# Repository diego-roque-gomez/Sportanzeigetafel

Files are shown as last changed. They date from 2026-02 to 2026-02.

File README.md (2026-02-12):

# Sports scoreboard
Development of a functional prototype for a sports scoreboard

This project was developed in collaboration with the sports department at Tecnológico de Monterrey and focused on the construction of an electronic scoreboard for the university's American football stadium.

## Requirements ##
- High visibility under outdoor lighting conditions
- Weather-resistant structure
- Secure mounting in the stadium cabin
- Remote control capability

## System overview ##
A functional prototype was designed, manufactured and submitted to the campus sports director for evaluation.

The system implemented an IoT-based architecture in which an ESP32 microcontroller received wireless commands from a web interface, enabling remote control of the scoreboard.

## Technical Contributions ##
- Design of a customised circuit board with multiple 7-segment displays and 8x8 LED matrices
- Implementation of MAX7219 drivers for efficient display control and GPIO optimisation
- Hardware integration with ESP32
- Collaboration on the design of a retractable mechanical mechanism for deployment and environmental protection

## Images
### PCB
Front_view_of_the_PCB
Rear_view_of_the_PCB
PCB_Layout

### Prototype
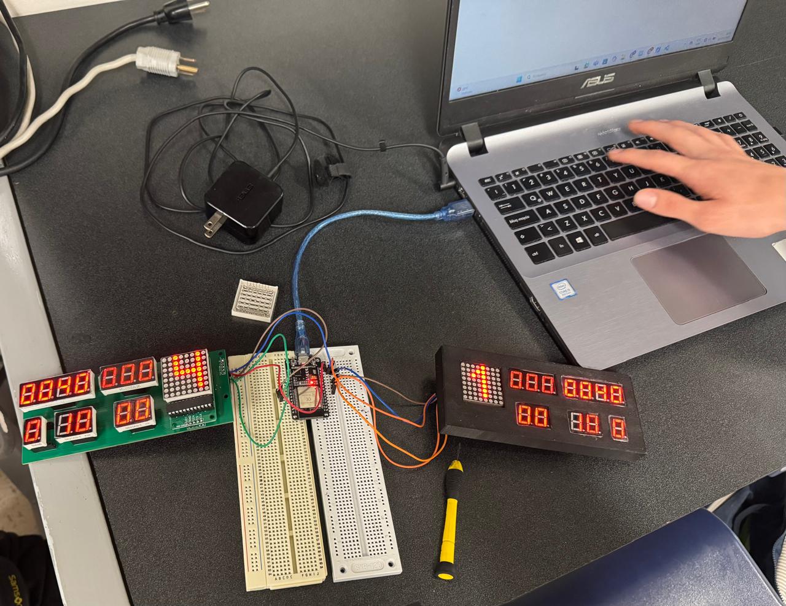
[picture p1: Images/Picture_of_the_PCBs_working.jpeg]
Picture of the PCBs working

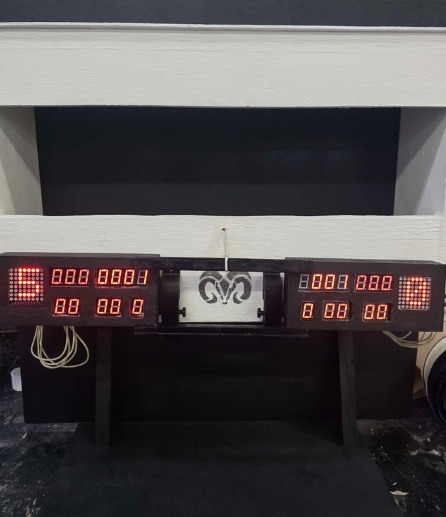
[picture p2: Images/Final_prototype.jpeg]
Final Prototype


## Demonstration videos

[Video_of_the_PCB_working](https://github.com/user-attachments/assets/36a9706f-3883-4caf-9d38-b58036e7d53b)

[Video of the final prototype](https://github.com/user-attachments/assets/bcdd5858-99ae-4861-a208-e2463b085100)

## System Architecture & Team Responsibilities

The project was developed collaboratively with clearly defined responsibilities:

- **PCB design and Electronic Integration:**

  Diego Roque Gómez

- **Financial proposal design for the project:**
  
  César Santiago Marín Barrera (included with permission)
  
  David Martínez Millán (included with permission)

- **Prototype assembly and installation:**

  Antoine Aramis Guzmán Rocha (included with permission)

- **Mechanical CAD design (SolidWorks):**
  
  Rodrigo Pérez Cázares (included with permission)
  
  Antoine Aramis Guzmán Rocha (included with permission)
  
  Diego Roque Gómez
  
- **Design and programming of the web interface and ESP32:**

  Rodrigo Pérez Cázares

## Mechanical design
The mechanical structure was developed collaboratively through iterative design cycles.

Individual components were modeled separately and later integrated into a unified assembly. The team continuously refined structural supports, mounting brackets, enclosure elements, and deployment mechanisms to ensure stability, weather resistance, and safe installation in the stadium cabin.

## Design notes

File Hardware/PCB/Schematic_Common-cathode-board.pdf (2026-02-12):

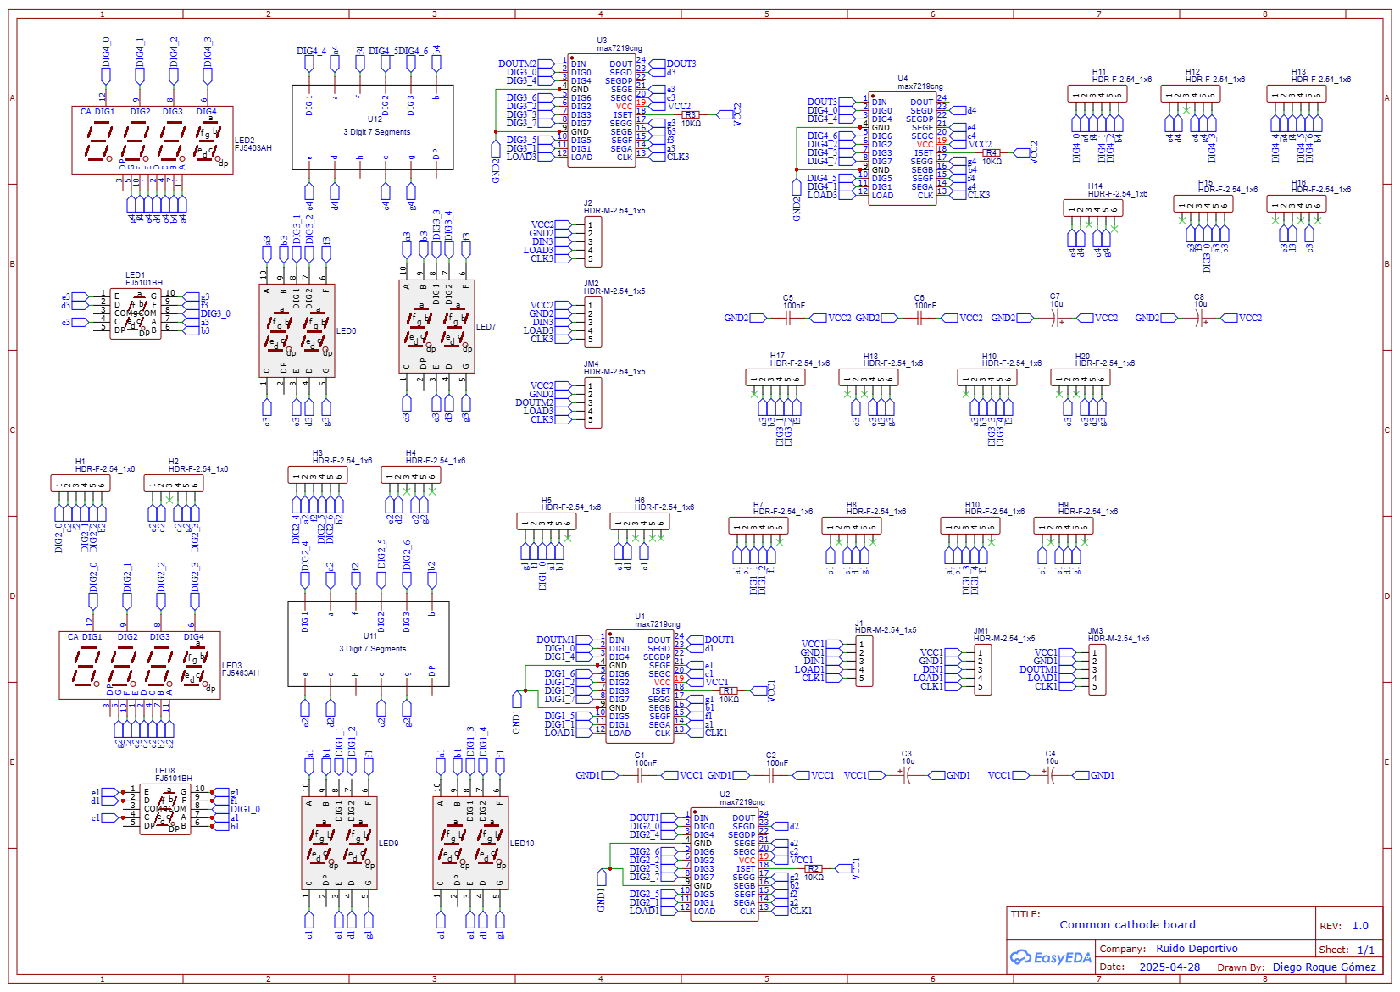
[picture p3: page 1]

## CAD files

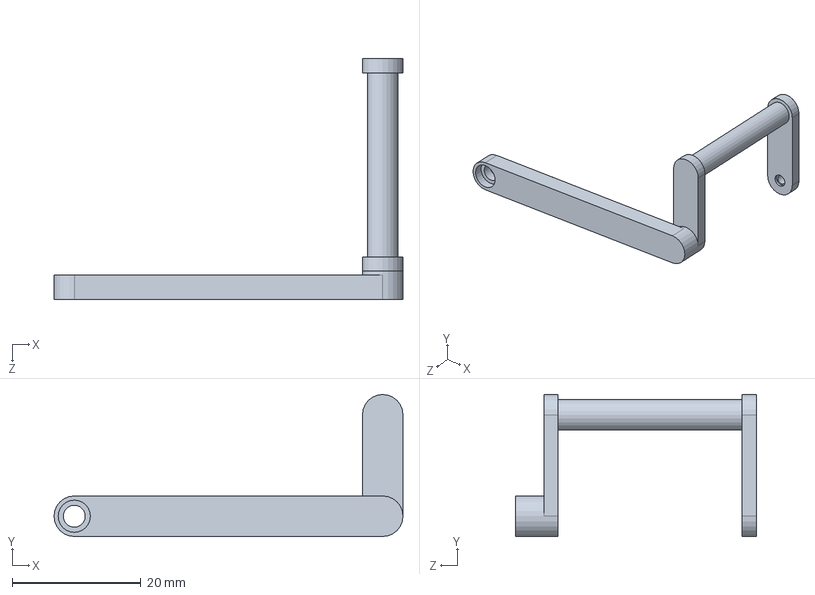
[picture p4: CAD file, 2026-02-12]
barra izquierda 1.SLDPRT
54.2 x 22.0 x 37.4 mm

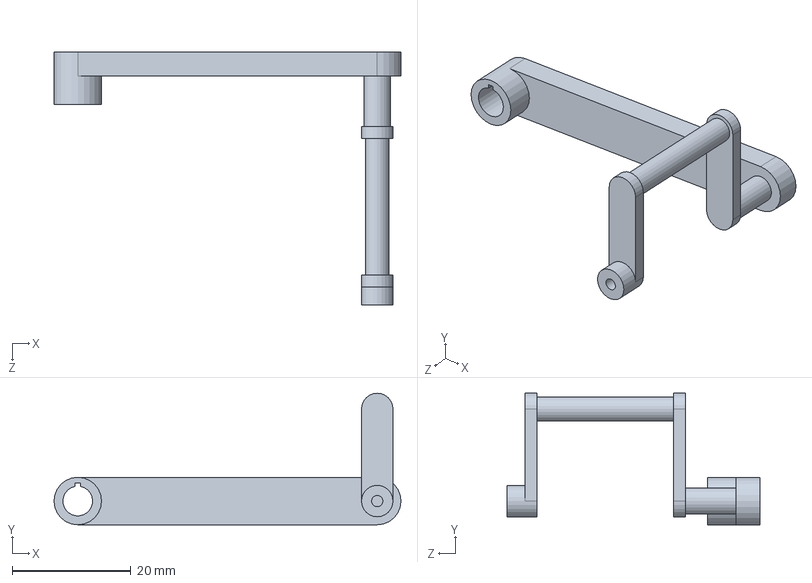
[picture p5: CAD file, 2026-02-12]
CAD/barra derecha 1.SLDPRT
58.4 x 22.1 x 42.5 mm

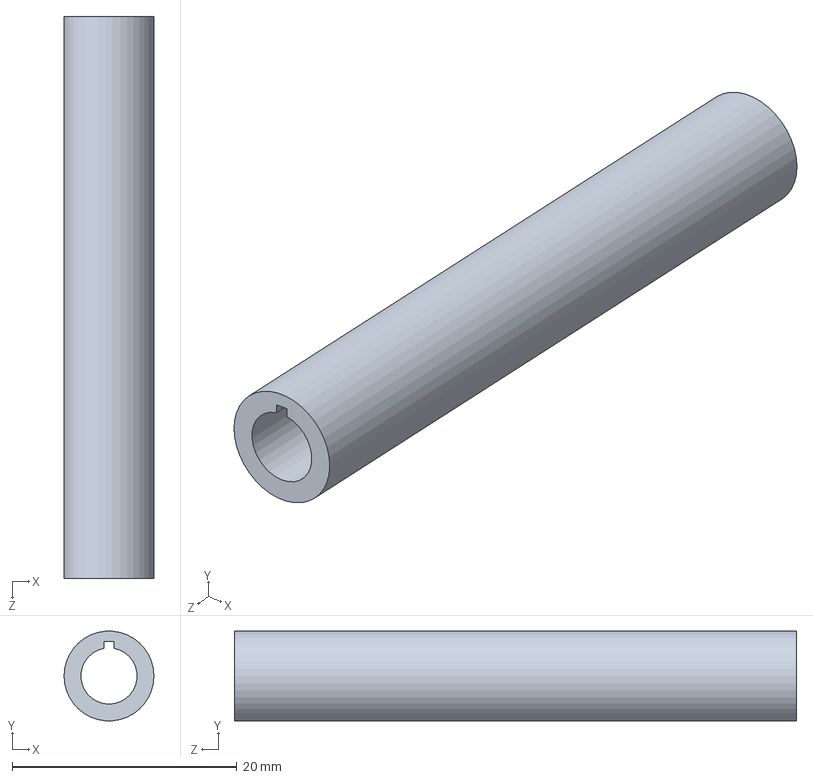
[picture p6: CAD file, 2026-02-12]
Hardware/CAD/broche.SLDPRT
8.00 x 7.97 x 50.0 mm

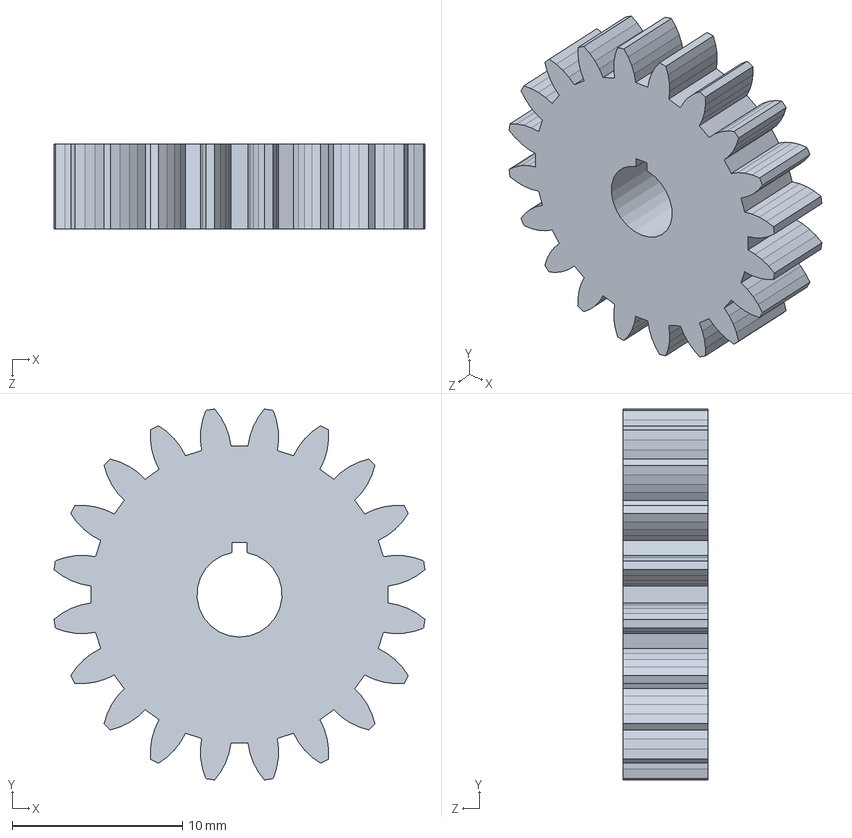
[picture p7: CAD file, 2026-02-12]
CAD/engrane 1.SLDPRT
21.8 x 21.8 x 5.00 mm

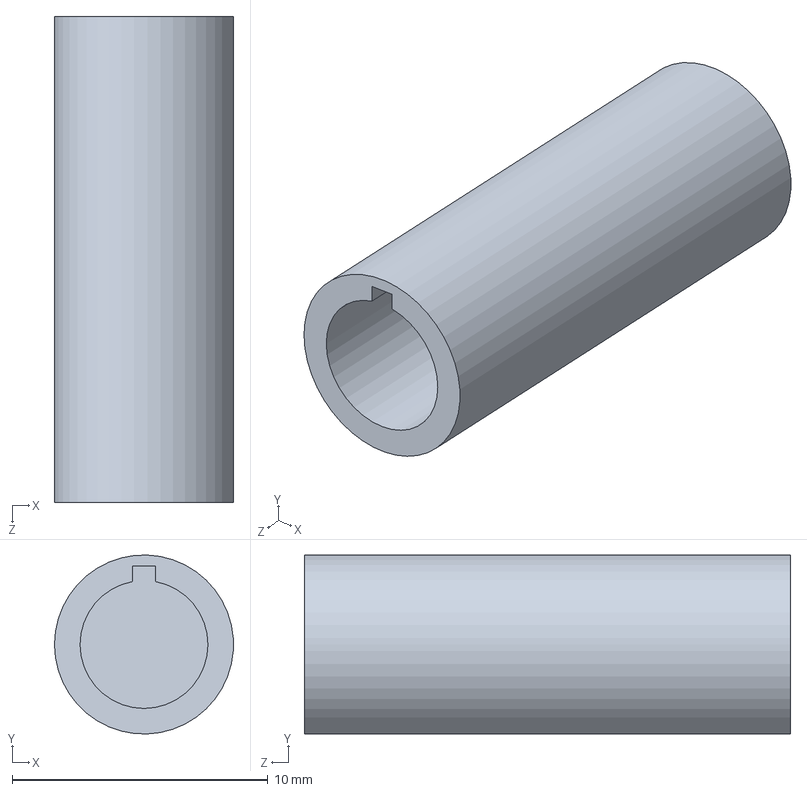
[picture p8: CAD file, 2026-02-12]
Hardware/CAD/seguro (2024).SLDPRT
7.00 x 7.00 x 19.0 mm

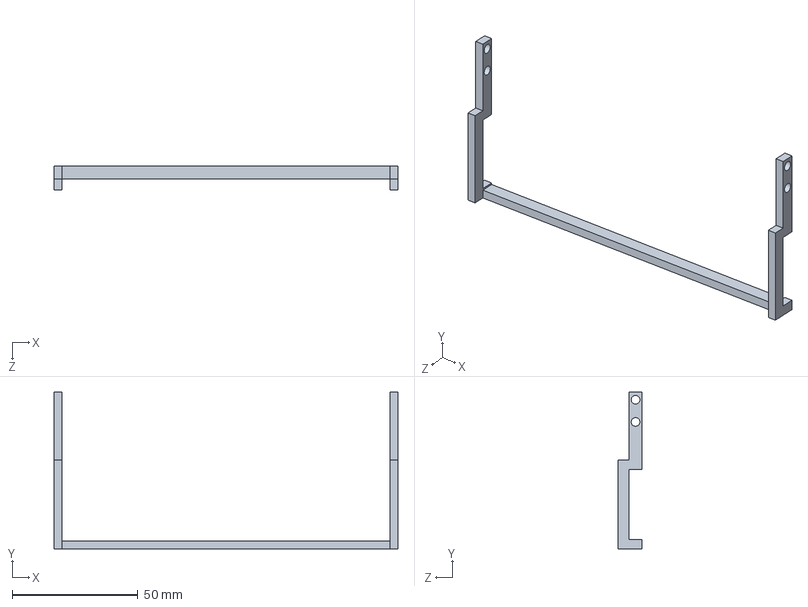
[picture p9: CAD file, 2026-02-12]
Soporte ambos tableros.SLDPRT
136.7 x 62.2 x 9.45 mm

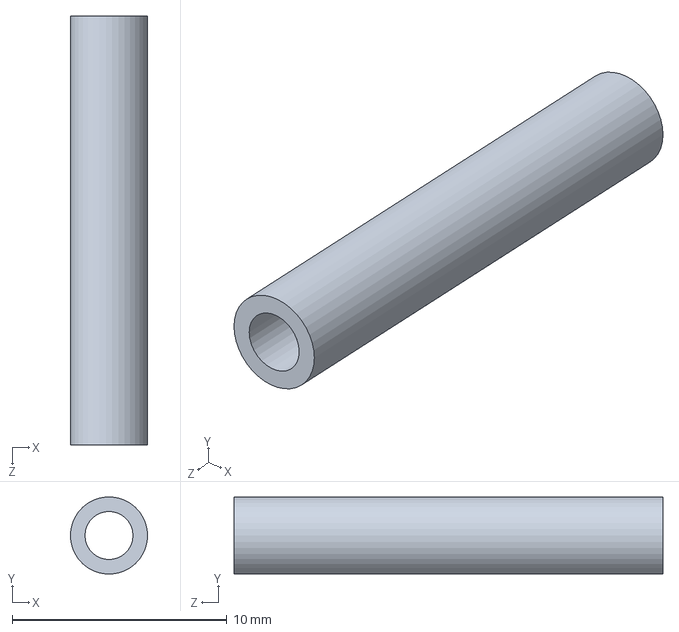
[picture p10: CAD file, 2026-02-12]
Hardware/CAD/Soporte_nuevo.SLDPRT
3.60 x 3.59 x 20.0 mm

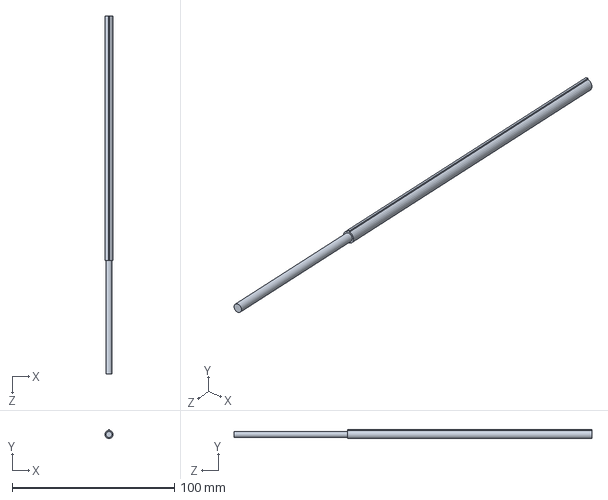
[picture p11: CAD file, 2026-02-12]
Hardware/CAD/ejesote.SLDPRT
4.97 x 5.54 x 220.6 mm

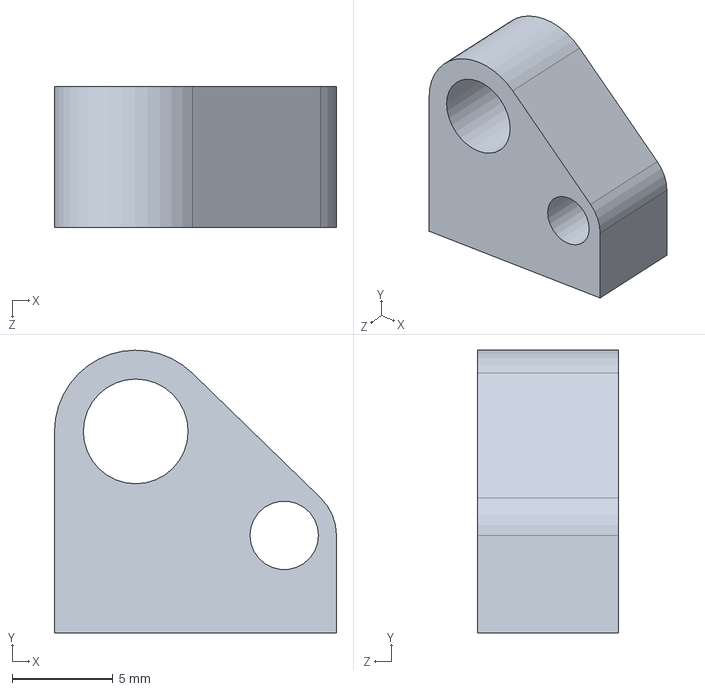
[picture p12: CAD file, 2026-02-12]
CAD/soporte.SLDPRT
14.0 x 14.0 x 7.00 mm

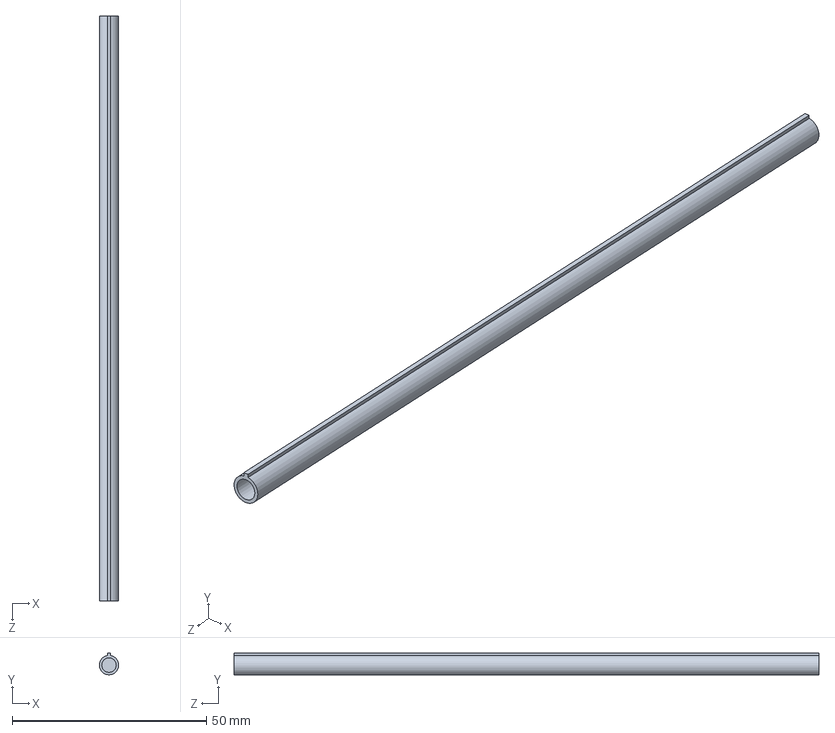
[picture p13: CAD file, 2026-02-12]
Hardware/CAD/ejesote 1.SLDPRT
5.00 x 5.54 x 150.6 mm

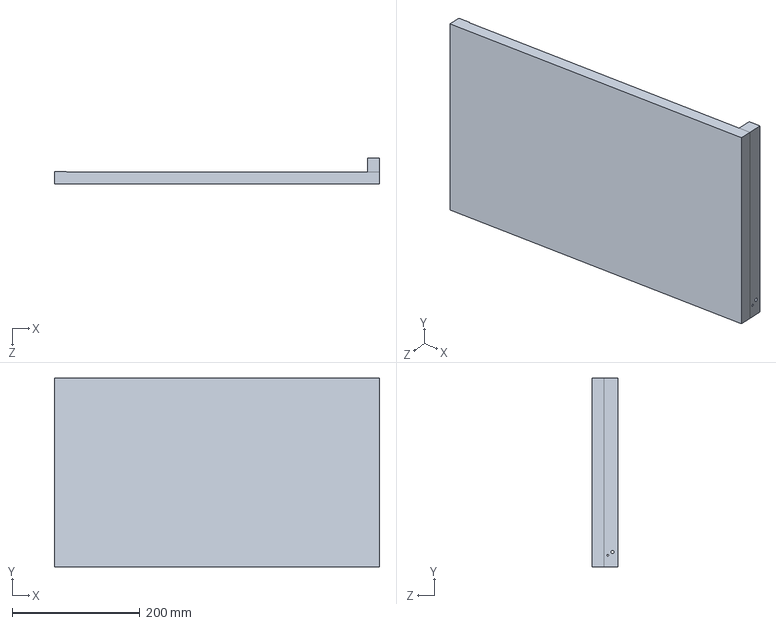
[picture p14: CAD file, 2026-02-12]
tabero.SLDPRT
509.7 x 296.1 x 41.4 mm

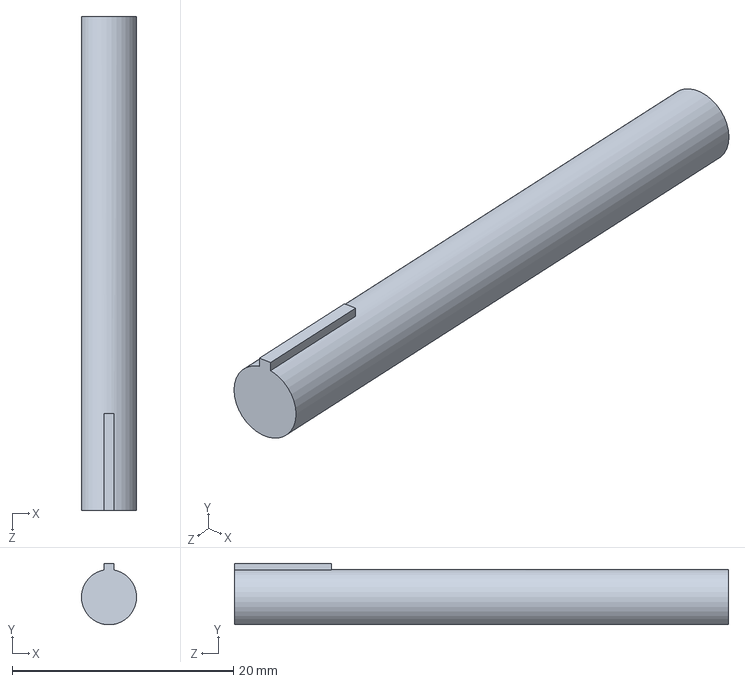
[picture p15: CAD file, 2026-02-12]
Hardware/CAD/eje pequeño.SLDPRT
5.00 x 5.55 x 44.7 mm

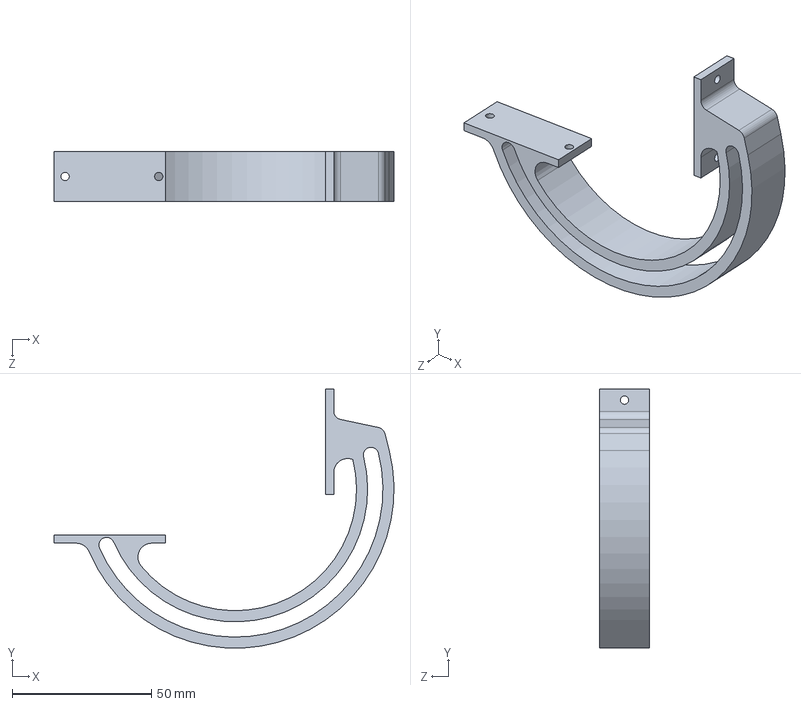
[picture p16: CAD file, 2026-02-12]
Hardware/CAD/Guia.SLDPRT
122.3 x 93.1 x 18.0 mm

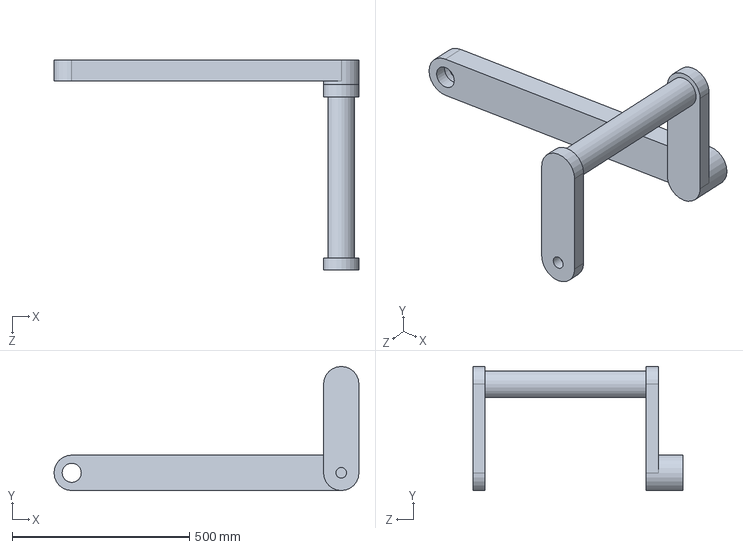
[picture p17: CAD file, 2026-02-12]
Hardware/CAD/barra izwuierda 2.SLDPRT
860.0 x 350.0 x 593.3 mm

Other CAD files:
Ensamblaje2.SLDASM
barra derecha 2.SLDPRT
CAD/Pieza1.SLDPRT
CAD/engrane 2.SLDPRT
Hardware/CAD/Soporte_nuevo224.SLDPRT
Hardware/CAD/Soporte_nuevo253.SLDPRT
Hardware/CAD/tablero2.SLDPRT

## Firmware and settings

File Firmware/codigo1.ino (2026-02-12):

#include <WiFi.h>
#include <WebServer.h>
#include <DNSServer.h>
#include <MD_Parola.h>
#include <MD_MAX72XX.h>
#include <SPI.h>
#include <ESP32Servo.h>

#define HARDWARE_TYPE MD_MAX72XX::DR0CR0RR1_HW

//Información de la red wifi
const char* ssid = "ControlEstadio";
const char* password = "56781234";

//Dominio para acceder a los controles desde el explorador
const char* domain = "control.pantalla";

//Pines a utilizar
const uint8_t DATA_PINLocal = 14;
const uint8_t DATA_PINVisitante = 5; 
const uint8_t CLK_PINLocal = 33;
const uint8_t CS_PINLocal = 26;
const uint8_t CLK_PINVisitante = 19;
const uint8_t CS_PINVisitante = 18;
const uint8_t servoPinVisita = 22;
const uint8_t servoPinLocal = 21 ;
const uint8_t pinavancepolea = 13;
const uint8_t pinguardarpolea = 2;

Servo servo1;
Servo servo2;

//Instancia matriz led
MD_MAX72XX local(HARDWARE_TYPE, DATA_PINLocal, CLK_PINLocal, CS_PINLocal, 3);
MD_MAX72XX visitante(HARDWARE_TYPE, DATA_PINVisitante, CLK_PINVisitante, CS_PINVisitante, 3);

//Servidores
WebServer server(80);
DNSServer dnsServer;

//Buffer para guardar html
char bufferhtml[65536];

const uint8_t numerosmatriz[10][3] = {
  {0x7F, 0x41, 0x7F},  // 0
  {0x40, 0x7F, 0x42},  // 1
  {0x4F, 0x49, 0x79},  // 2
  {0x36, 0x49, 0x49},  // 3
  {0x7F, 0x0A, 0x0C},  // 4
  {0x79, 0x49, 0x4F},  // 5
  {0x79, 0x49, 0x7F},  // 6
  {0x7F, 0x01, 0x03},  // 7
  {0x7F, 0x49, 0x7F},  // 8
  {0x7F, 0x09, 0x0F}   // 9
};

const uint8_t numerosdisplay[10] = {
  0x7E,  // 0 01111110
  0x30,  // 1 00110000
  0x6D,  // 2 01101101
  0x79,  // 3 01111001
  0x33,  // 4 00110011
  0x5B,  // 5 01011011
  0x5F,  // 6 01011111
  0x70,  // 7 01110000
  0x7F,  // 8 01111111
  0x7B   // 9 01111011
};


bool running = false;
bool pausa = false;
bool cronometro;

int minutos = 0;
int segundos = 0;
uint32_t tiempo = 0;
uint32_t tiempoAnterior = 0;
uint32_t tiempoActual = 0; 

uint16_t v1 = 0;
uint16_t v2= 0;
uint16_t v3= 0;
uint16_t v4= 0;
uint16_t v5= 0;
uint16_t v6= 0;
uint16_t v7= 0;
uint16_t v8= 0;
uint16_t v9= 0;
uint16_t v10= 0;

// Código html
const char* html PROGMEM = R"rawliteral(
<!DOCTYPE html>
<html lang="es">
<head>
  <meta charset="UTF-8">
  <title>Controles estadio</title>
  <style>
    input[type="number"]::-webkit-inner-spin-button,
    input[type="number"]::-webkit-outer-spin-button {
      -webkit-appearance: none;
      margin: 0;
    }

    html, body {
      margin: 0;
      padding: 0;
      height: 100%%;
      overflow: hidden;
      position: relative;
    }

    img.fondo {
      width: 100vw;
      height: 100vh;
      object-fit: fill;
      position: fixed;
      top: 0;
      left: 0;
      z-index: -1;
    }

    .input-personalizado {
      position: absolute;
      padding: 5px;
      font-size: 16px;
      text-align: center;
      border: 1px solid #ccc;
      background-color: rgba(255, 255, 255, 0.8);
      box-shadow: 2px 2px 8px rgba(0, 0, 0, 0.15);
      transition: all 0.2s ease;
    }

    .input-personalizado:focus {
      border-color: #4a90e2;
      box-shadow: 0 0 10px rgba(74, 144, 226, 0.4);
      outline: none;
      background-color: white;
    }

  </style>
</head>
<body>
  <img class="fondo" src="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
void loop(){
  dnsServer.processNextRequest();
  server.handleClient();

  if(running){
    tiempoActual = millis();
    if (tiempoActual - tiempoAnterior >= 1000){
      tiempoAnterior = tiempoActual;
      if(cronometro){
        tiempo++;
      }
      else{
        if(tiempo>0){
        tiempo--;
        }
        else{
          running = false;
        }
      }
    }
  actualizar_display(tiempo);
  }

}

void handleMenu(){
  snprintf(bufferhtml, sizeof(bufferhtml), html, running ? "true" : "false" , tiempo, cronometro ? 1 : -1,  v1, v2, v3, v4, v5, v6, v7, v8, v9, v10);
  server.send(200, "text/html", bufferhtml);
}

void handleForm(){
  v1 = server.arg("numero1").toInt();
  v2 = server.arg("numero2").toInt();
  v3 = server.arg("numero3").toInt();
  v4 = server.arg("numero4").toInt();
  v5 = server.arg("numero5").toInt();
  v6 = server.arg("numero6").toInt();
  v7 = server.arg("numero7").toInt();
  v8 = server.arg("numero8").toInt();
  v9 = server.arg("numero9").toInt();
  v10 = server.arg("numero10").toInt();

  local.clear();
  visitante.clear();
  delay(10);
  Serial.println(v1);
  dibujarmatriz_local(v1);
  dibujarmatriz_visitante(v10);
  displays_local(v2, v3, v4, v5);
  displays_visitante(v9, v7, v8, v6);
  

  
  server.sendHeader("Location", "/");
  server.send(302);
}

void handleInicio(){

  if(running){
    server.sendHeader("Location", "/");
    server.send(302);
    return;
  }

  if(!pausa){
    minutos = server.arg("minutes").toInt();
    segundos = server.arg("seconds").toInt();
    tiempo = minutos*60 + segundos;
    if(tiempo == 0){
      cronometro = true;
    }
    else{
      cronometro = false;
      pausa = false;
    }
  }
  else{
    pausa = false;
  }
  tiempoAnterior = millis();
  running = true;
  
  server.sendHeader("Location", "/");
  server.send(302);

}

void handlePausa(){
  running = false;
  pausa = true;
  
  server.sendHeader("Location", "/");
  server.send(302);
  
}

void handleReset(){
  running = false;
  pausa = false;
  minutos = 0;
  segundos = 0;
  tiempo = 0;

  local.setColumn(23, numerosdisplay[0]);
  local.setColumn(22, numerosdisplay[0]);
  local.setColumn(21, numerosdisplay[0]);
  local.setColumn(20, numerosdisplay[0]);
  
  visitante.setColumn(23, numerosdisplay[0]);
  visitante.setColumn(22, numerosdisplay[0]);
  visitante.setColumn(21, numerosdisplay[0]);
  visitante.setColumn(20, numerosdisplay[0]);
  
  
  server.sendHeader("Location", "/");
  server.send(302);

}

void handleServo(){
  if (server.method() == HTTP_POST){
    int valor_servo = server.arg("servo").toInt();
    int n = 3;
    if (valor_servo == 0){
      // Guardar mecanismo
      // Bajar polea
      digitalWrite(pinavancepolea, LOW);
      digitalWrite(pinguardarpolea, LOW);
      delay(500);
      digitalWrite(pinguardarpolea, HIGH);
      digitalWrite(pinavancepolea, LOW);
      delay(2500); 
      digitalWrite(pinguardarpolea, LOW);
      digitalWrite(pinavancepolea, LOW);

      // Bajar servos
      for (int posicion = 0; posicion <= 60; posicion++){

        // Este debe llegar a 0
        servo1.write(180 - posicion);
        // Este debe llegar a 180
        servo2.write(posicion);
        delay(15);
      }

      //Segundo ciclo
      digitalWrite(pinavancepolea, LOW);
      digitalWrite(pinguardarpolea, LOW);
      delay(500);
      digitalWrite(pinguardarpolea, HIGH);
      digitalWrite(pinavancepolea, LOW);
      delay(2500); 
      digitalWrite(pinguardarpolea, LOW);
      digitalWrite(pinavancepolea, LOW);

      // Bajar servos
      for (int posicion = 60; posicion <= 120; posicion++){

        // Este debe llegar a 0
        servo1.write(180 - posicion);
        // Este debe llegar a 180
        servo2.write(posicion);
        delay(15);
      }

      // Bajar servos
      for (int posicion = 120; posicion <= 180; posicion++){

        // Este debe llegar a 0
        servo1.write(180 - posicion);
        // Este debe llegar a 180
        servo2.write(posicion);
        delay(15);
      }
 
    
    }
      
    else if (valor_servo == 1){
      //Subir mecanismo
      // Subir servos
      for (int posicion = 0; posicion <= 180; posicion++){
        // Este debe llegar a 180
        servo1.write(posicion);
        // Este debe llegar a 0
        servo2.write(180 - posicion);
        delay(15);
      }

      //Subir polea
      digitalWrite(pinavancepolea, LOW);
      digitalWrite(pinguardarpolea, LOW);
      delay(500);
      digitalWrite(pinguardarpolea, LOW);
      digitalWrite(pinavancepolea, HIGH);
      delay(5150);
      digitalWrite(pinguardarpolea, LOW);
      digitalWrite(pinavancepolea, LOW);
      delay(200);
      
    } 
  }
  server.sendHeader("Location", "/");
  server.send(302);
}

// Toma un número de segundos y los escribe en forma mm:ss en un display de 7 segmentos

void actualizar_display(uint32_t tiempo){
  int minutos = tiempo / 60;
  int segundos = tiempo % 60;

  int digito1 = minutos / 10;
  int digito2 = minutos % 10;
  int digito3 = segundos / 10;
  int digito4 = segundos % 10;

  local.setColumn(23, numerosdisplay[digito1]);
  local.setColumn(22, numerosdisplay[digito2]);
  local.setColumn(21, numerosdisplay[digito3]);
  local.setColumn(20, numerosdisplay[digito4]);

  visitante.setColumn(23, numerosdisplay[digito1]);
  visitante.setColumn(22, numerosdisplay[digito2]);
  visitante.setColumn(21, numerosdisplay[digito3]);
  visitante.setColumn(20, numerosdisplay[digito4]);

  

}

// Dibuja la matriz led del puntaje
void dibujarmatriz_local(int puntos){
  if (puntos<10){
    local.setChar(5, puntos+48);
  }
  else if (puntos<100){
    int decenas = puntos/10;
    int unidades = puntos%10;

    for(uint8_t i = 0; i<3; i++){
      local.setColumn(i+5, numerosmatriz[decenas][i]);
    }
    for (uint8_t i = 0; i < 3; i++) {
    local.setColumn(i, numerosmatriz[unidades][i]);
    }
  }
  else{
    local.setChar(5, 48);
  }
}

void dibujarmatriz_visitante(int puntos){

  if (puntos<10){
    visitante.setChar(5, puntos+48);
  }
  else if (puntos<100){
    int decenas = puntos/10;
    int unidades = puntos%10;

    for(uint8_t i = 0; i<3; i++){
      visitante.setColumn(i+5, numerosmatriz[decenas][i]);
    }
    for (uint8_t i = 0; i < 3; i++) {
    visitante.setColumn(i, numerosmatriz[unidades][i]);
    }
  }
  else{
    visitante.setChar(5, 48);
  }

}

void displays_local(int faltas, int togo, int ballon, int periodo){

  if (faltas>999) faltas = 0;
  if (togo>99) togo = 0;
  if (ballon>99) togo = 0;
  if (periodo>9) periodo = 0;

  int dig1_faltas = faltas/100;
  int dig2_faltas = faltas/10%10;
  int dig3_faltas = faltas%10;

  int dig1_togo = togo/10;
  int dig2_togo = togo%10;

  int dig1_ballon = ballon/10;
  int dig2_ballon = ballon%10;

  local.setColumn(19, numerosdisplay[dig1_faltas]);
  local.setColumn(18, numerosdisplay[dig2_faltas]);
  local.setColumn(17, numerosdisplay[dig3_faltas]);

  local.setColumn(11, numerosdisplay[dig2_togo]);
  local.setColumn(12, numerosdisplay[dig1_togo]);

  local.setColumn(13, numerosdisplay[dig2_ballon]);
  local.setColumn(14, numerosdisplay[dig1_ballon]);

  local.setColumn(15, numerosdisplay[periodo]);
  
}

void displays_visitante(int faltas, int togo, int ballon, int periodo){

  if (faltas>999) faltas = 0;
  if (togo>99) togo = 0;
  if (ballon>99) togo = 0;
  if (periodo>9) periodo = 0;

  
  int dig1_faltas = faltas/100;
  int dig2_faltas = faltas/10%10;
  int dig3_faltas = faltas%10;

  int dig1_togo = togo/10;
  int dig2_togo = togo%10;

  int dig1_ballon = ballon/10;
  int dig2_ballon = ballon%10;

  visitante.setColumn(19, numerosdisplay[dig1_faltas]);
  visitante.setColumn(18, numerosdisplay[dig2_faltas]);
  visitante.setColumn(17, numerosdisplay[dig3_faltas]);

  visitante.setColumn(13, numerosdisplay[dig2_togo]);
  visitante.setColumn(14, numerosdisplay[dig1_togo]);

  visitante.setColumn(11, numerosdisplay[dig2_ballon]);
  visitante.setColumn(12, numerosdisplay[dig1_ballon]);

  visitante.setColumn(15, numerosdisplay[periodo]);
  
}

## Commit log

2026-02-12 Rename barra derecha 1.SLDPRT to CAD/barra derecha 1.SLDPRT
    [barra derecha 1.SLDPRT]
2026-02-12 Rename barra izwuierda 2.SLDPRT to CAD/barra izwuierda 2.SLDPRT
    [barra izwuierda 2.SLDPRT]
2026-02-12 Rename ejesote 1.SLDPRT to CAD/ejesote 1.SLDPRT
    [ejesote 1.SLDPRT]
2026-02-12 Rename engrane 1.SLDPRT to CAD/engrane 1.SLDPRT
    [engrane 1.SLDPRT]
2026-02-12 Rename engrane 2.SLDPRT to CAD/engrane 2.SLDPRT
    [engrane 2.SLDPRT]
2026-02-12 Rename CAD/barra izwuierda 2.SLDPRT to Hardware/CAD/barra izwuierda 2.SLDPRT
    [barra izwuierda 2.SLDPRT]
2026-02-12 Rename CAD/eje pequeño.SLDPRT to Hardware/CAD/eje pequeño.SLDPRT
    [eje pequeño.SLDPRT]
2026-02-12 Rename CAD/ejesote 1.SLDPRT to Hardware/CAD/ejesote 1.SLDPRT
    [ejesote 1.SLDPRT]
2026-02-12 Rename CAD/seguro (2024).SLDPRT to Hardware/CAD/seguro (2024).SLDPRT
    [seguro (2024).SLDPRT]
